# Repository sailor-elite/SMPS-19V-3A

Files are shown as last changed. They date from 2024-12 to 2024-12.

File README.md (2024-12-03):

# SMPS SPECIFICATIONS
- Input Voltage: 230V AC (rectified to ~325V DC)
- Output Voltage: 19V DC
- Output Current: 3A
- Output Power: Up to 60W (maximum)

# SCHEMATIC DIAGRAM

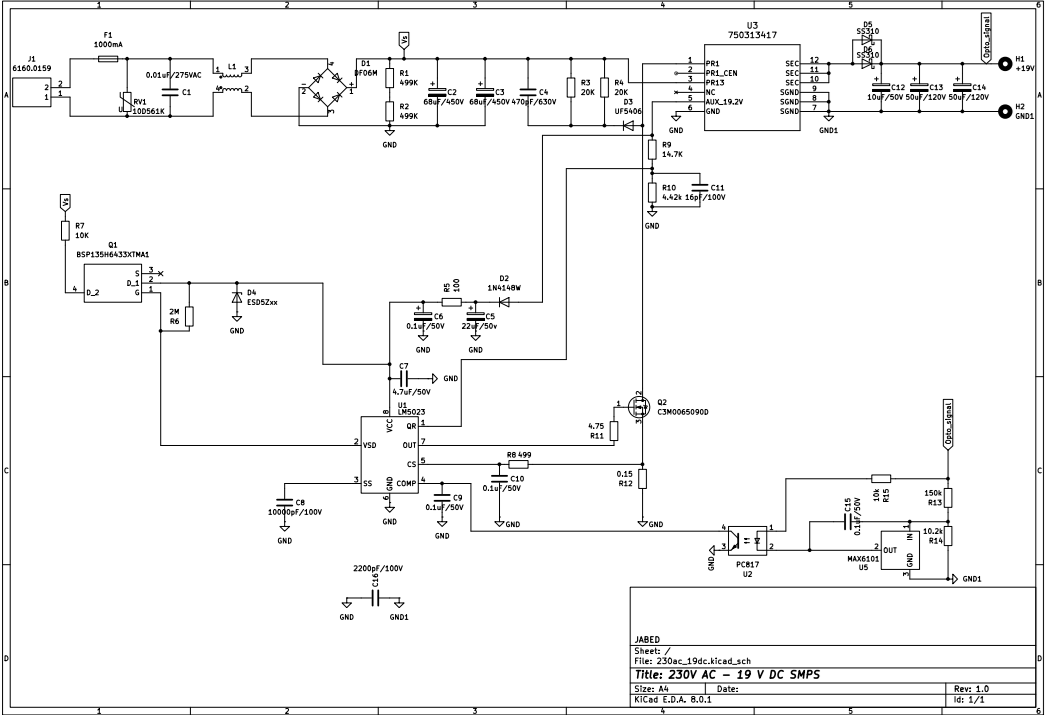
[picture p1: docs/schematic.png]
Schematic


# PCB 3D VIEW

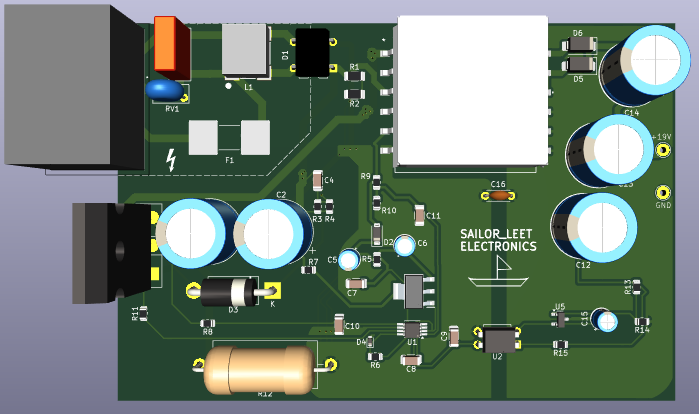
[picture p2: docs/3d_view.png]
PCB_3D_VIEW


# CALCULATION

### Transformer Turns Ratio Calculation

To determine the turns ratio of a transformer, use the following formula:

Np / Ns = Vin / (Vout + Vd)

Where:  
- **\(N_p\)**: Number of primary winding turns  
- **\(N_s\)**: Number of secondary winding turns  
- **\(V_in\)**: Input voltage to the transformer (325V DC in this example)  
- **\(V_out\)**: Desired output voltage (19V DC in this case)  
- **\(V_d\)**: Voltage drop across the secondary diode (approximately 0.5V for a Schottky diode)  

#### Example Calculation:

For an output voltage of 19V:

Np / Ns = 325V / (19V + 0.5V)

Np / Ns = 325 / 19.5 ≈ 16.66

Thus, the primary-to-secondary turns ratio is approximately **17:1**.

### Turns Ratio Calculation

The number of primary turns (**Np**) can be calculated using the volt-second balance equation:

Np = (Vin × ton) / (Bmax × Ae)

Where:  
- **Vin**: Input voltage (325V)  
- **ton**: On-time of the switch (calculated based on the duty cycle, typically 50% at maximum load)  
- **Bmax**: Maximum magnetic flux density (e.g., 2000 Gauss or 0.2T for ferrite cores)  
- **Ae**: Effective cross-sectional area of the core  

#### Example Calculation:

For a switching frequency of **130 kHz** (period = 7.7µs) and a 50% duty cycle, the on-time (\(ton\)) is:

ton = 50% of 7.7µs = 3.35µs

Assume the following parameters for an ETD39 core:  
- **Bmax = 0.2T**  
- **Ae = 125mm² (125 × 10⁻⁶ m²)**  

Substitute the values into the formula:

Np = (325V × 3.35µs) / (0.2T × 125 × 10⁻⁶ m²) Np ≈ 43.5 turns

Thus, the primary winding requires approximately **44 turns**.

### Number of Secondary Turns Calculation

Using the turns ratio and the calculated number of primary turns, the number of secondary turns (**Ns**) can be calculated as follows:

Ns = Np / Turns Ratio

Where:  
- **Np**: Number of primary turns (calculated previously as 85 turns)  
- **Turns Ratio**: Primary-to-secondary turns ratio (17:1 in this example)  

#### Example Calculation:

Substitute the values into the formula:

Ns = 44 / 17 Ns ≈ 2.5 turns

So the turns number is **3**.
### Reference Voltage

Using a voltage divider with resistors of **150 kΩ** and **10.2 kΩ** creates the following ratio:

Vout = Vin * (R_lower / (R_upper + R_lower))

Where:  
- **Vin**: Input voltage  
- **R_lower**: Resistor connected to the ground (10.2 kΩ)  
- **R_upper**: Resistor connected to the input voltage (150 kΩ)  

#### Example Calculation:

For an input voltage of **19V**:

Vout = 19V * (10.2 kΩ / (150 kΩ + 10.2 kΩ))

Vout = 19V * (10.2 / 160.2) ≈ 1.21V

This is very close to the reference voltage of the **MAX6101**, which is **1.25V**.

# COMPONENTS
| Component | Value | Package | Quantity |
|---|---|---|---|
| C1 | 0.01uF/275VAC  | Capacitor_THT:C_Rect_L10.0mm_W4.0mm_P7.50mm_MKS4 | 1 |
| C2, C3 | 68uF/450V | Capacitor_THT:CP_Radial_D12.5mm_P7.50mm | 2 |
| C4 | 470pF/630V | Capacitor_SMD:C_1206_3216Metric | 1 |
| C5 | 22uF/50V | Capacitor_THT:CP_Radial_D4.0mm_P2.00mm | 1 |
| C6, C9, C10, C15 | 0.1uF/50V | -- mixed values -- | 4 |
| C7 | 4.7uF/50V | Capacitor_SMD:C_1206_3216Metric | 1 |
| C8 | 10000pF/100V | Capacitor_SMD:C_1206_3216Metric | 1 |
| C11 | 16pF/100V | Capacitor_SMD:C_1206_3216Metric | 1 |
| C12 | 10uF/50V | Capacitor_THT:CP_Radial_D12.5mm_P7.50mm | 1 |
| C13, C14 | 50uF/120V | Capacitor_THT:CP_Radial_D12.5mm_P7.50mm | 2 |
| C16 | 2200pF/100V | Capacitor_THT:C_Disc_D4.3mm_W1.9mm_P5.00mm | 1 |
| D1 | DF06M | Diode_THT:Diode_Bridge_DIP-4_W7.62mm_P5.08mm | 1 |
| D2 | 1N4148W | Diode_SMD:D_SOD-123 | 1 |
| D3 | UF5406 | Diode_THT:D_DO-201AD_P15.24mm_Horizontal | 1 |
| D4 | ESD5Zxx | Diode_SMD:D_SOD-523 | 1 |
| D5, D6 | SS310 | Diode_SMD:D_SMA | 2 |
| F1 | 1000mA | Fuse:Fuse_Littelfuse-NANO2-462 | 1 |
| J1 | 6160.0159 | private:61600159 | 1 |
| L1 | L_Coupled_1342 | private:WE-SL5_HC | 1 |
| Q1 | BSP135H6433XTMA1| private:SOT230P700X180-4N | 1 |
| Q2 | C3M0065090D | Package_TO_SOT_THT:TO-247-3_Vertical | 1 |
| R1, R2 | 499K | Resistor_SMD:R_1206_3216Metric | 2 |
| R3, R4 | 20K | Resistor_SMD:R_0805_2012Metric | 2 |
| R5 | 100 | Resistor_SMD:R_0805_2012Metric | 1 |
| R6 | 2M | Resistor_SMD:R_0805_2012Metric | 1 |
| R7 | 10K | Resistor_SMD:R_0805_2012Metric | 1 |
| R8 | 499 | Resistor_SMD:R_0805_2012Metric | 1 |
| R9 | 14.7K | Resistor_SMD:R_0805_2012Metric | 1 |
| R10 | 4.42k | Resistor_SMD:R_0805_2012Metric | 1 |
| R11 | 4.75 | Resistor_SMD:R_0805_2012Metric | 1 |
| R12 | 0.15 | Resistor_THT:R_Axial_DIN0922_L20.0mm_D9.0mm_P25.40mm_Horizontal | 1 |
| R13 | 150k | Resistor_SMD:R_0805_2012Metric | 1 |
| R14 | 10.2k | Resistor_SMD:R_0805_2012Metric | 1 |
| R15 | 10k | Resistor_SMD:R_0805_2012Metric | 1 |
| RV1 | 10D561K | Varistor:RV_Disc_D7mm_W3.6mm_P5mm | 1 |
| U1 | LM5023 | Package_SO:VSSOP-8_3.0x3.0mm_P0.65mm | 1 |
| U2 | PC817 | Package_DIP:DIP-4_W7.62mm | 1 |
| U3 | 750313417 | private:SMD_13417_WRE | 1 |
| U5 | MAX6101 | Package_TO_SOT_SMD:SOT-23 | 1 |

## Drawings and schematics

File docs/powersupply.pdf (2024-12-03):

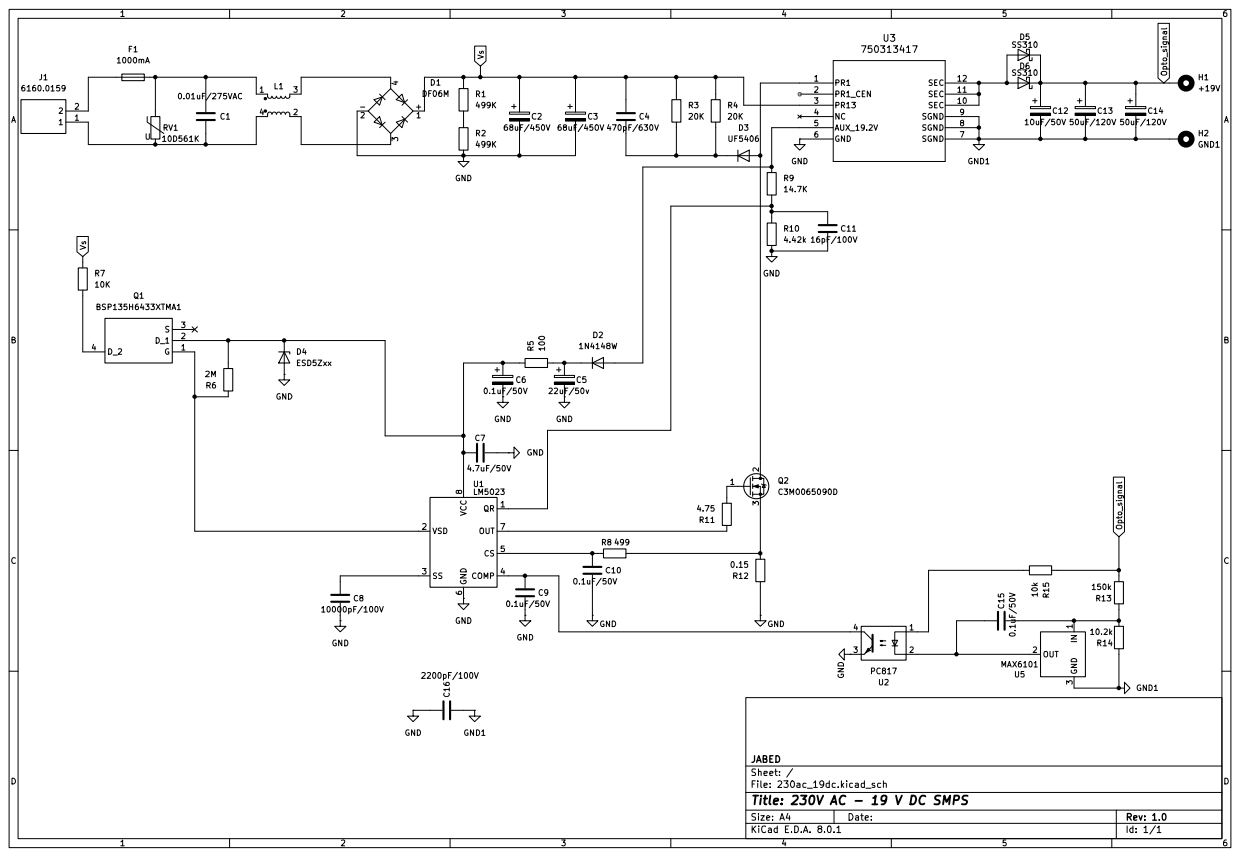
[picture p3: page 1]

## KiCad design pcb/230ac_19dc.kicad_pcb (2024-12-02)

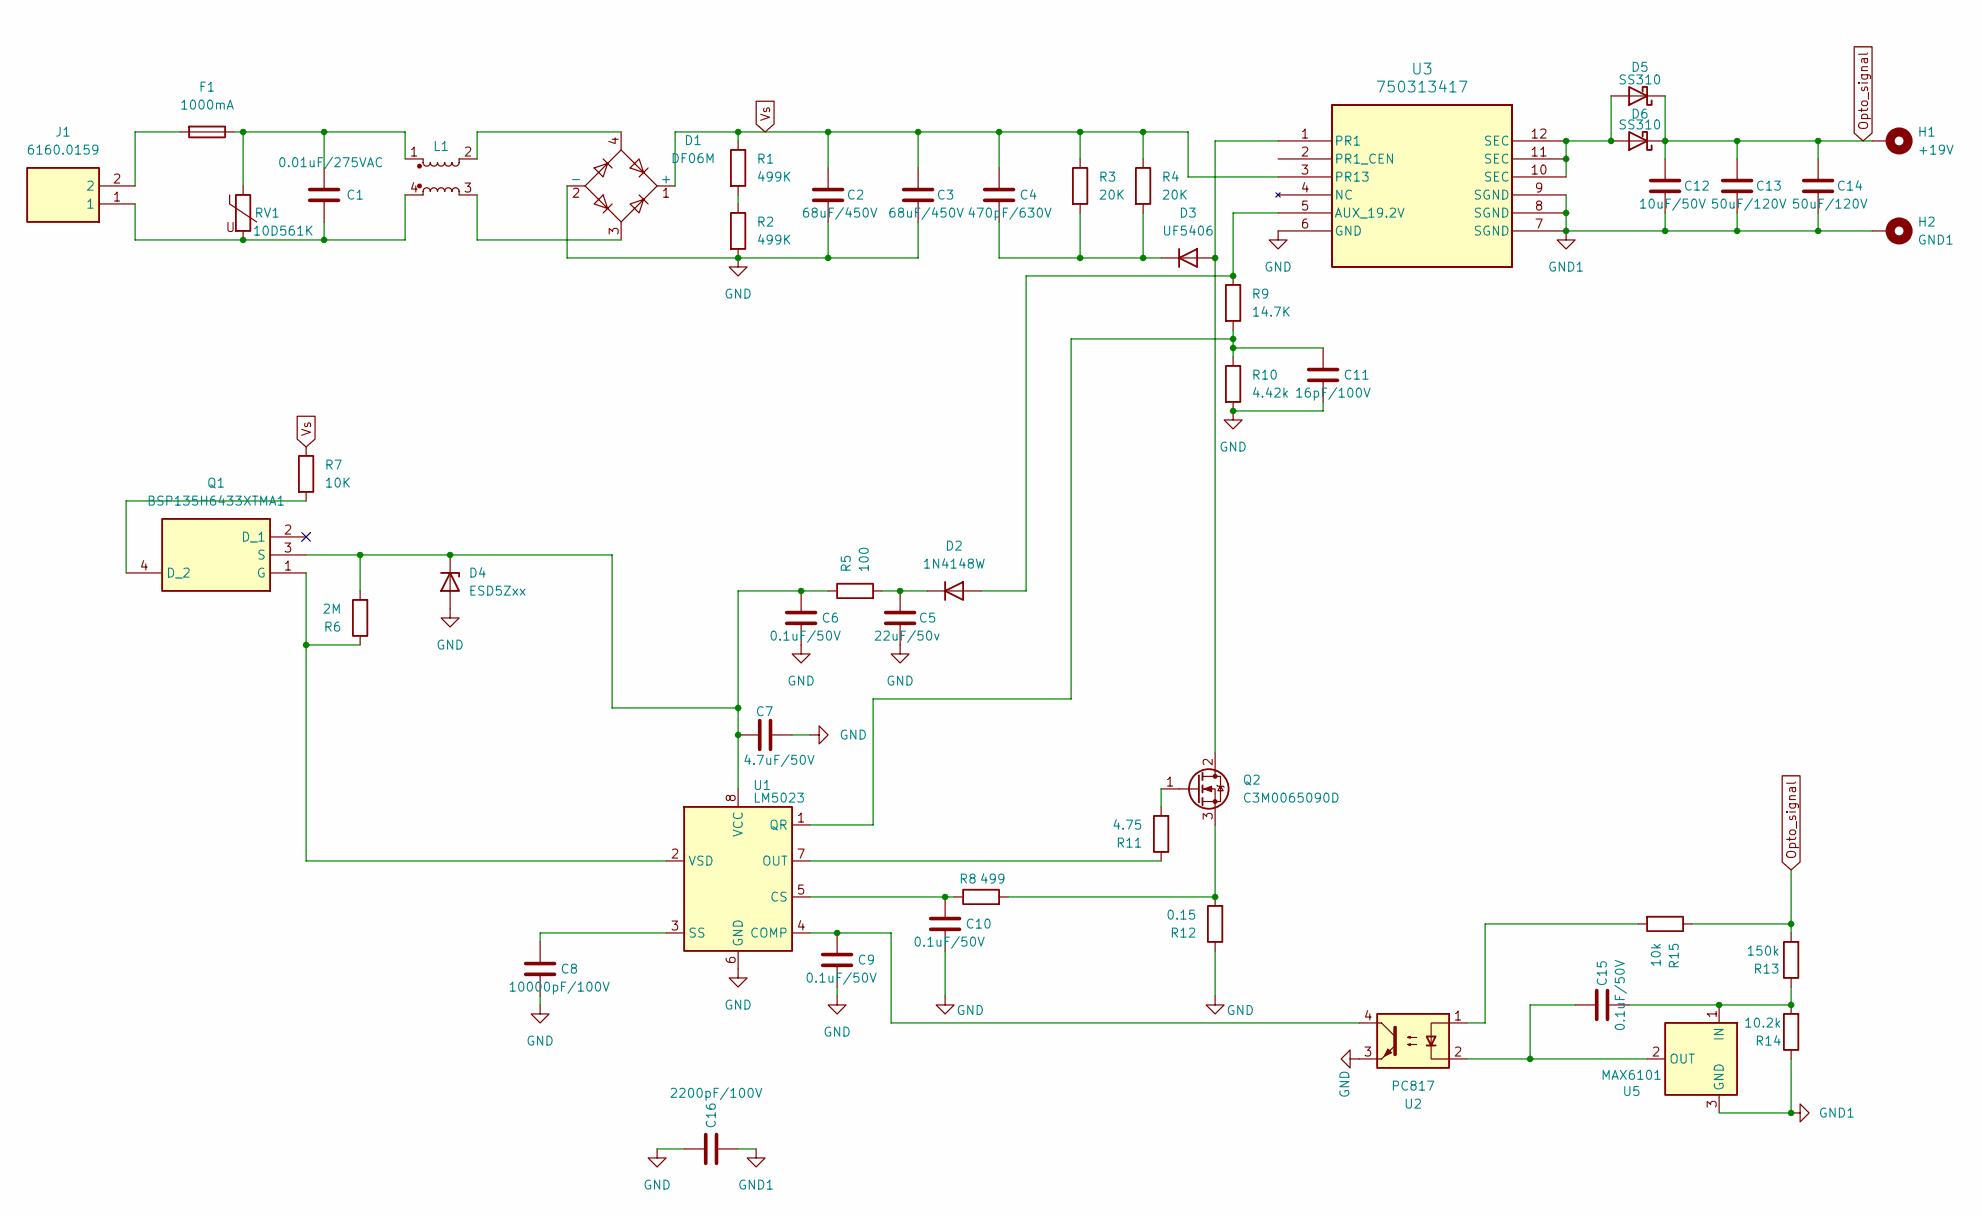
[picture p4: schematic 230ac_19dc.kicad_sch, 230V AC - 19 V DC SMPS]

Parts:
C1: 0.01uF/275VAC; C_Rect_L10.0mm_W4.0mm_P7.50mm_MKS4
C2, C3: 68uF/450V; CP_Radial_D12.5mm_P7.50mm
C4: 470pF/630V; C_1206_3216Metric
C5: 22uF/50v; CP_Radial_D4.0mm_P2.00mm
C6, C15: 0.1uF/50V; CP_Radial_D4.0mm_P2.00mm
C7: 4.7uF/50V; C_1206_3216Metric
C8: 10000pF/100V; C_1206_3216Metric
C9, C10: 0.1uF/50V; C_1206_3216Metric
C11: 16pF/100V; C_1206_3216Metric
C12: 10uF/50V; CP_Radial_D12.5mm_P7.50mm
C13, C14: 50uF/120V; CP_Radial_D12.5mm_P7.50mm
C16: 2200pF/100V; C_Disc_D4.3mm_W1.9mm_P5.00mm
D1: DF06M; Diode_Bridge_DIP-4_W7.62mm_P5.08mm
D2: 1N4148W; D_SOD-123
D3: UF5406; D_DO-201AD_P15.24mm_Horizontal
D4: ESD5Zxx; D_SOD-523
D5, D6: SS310; D_SMA
F1: 1000mA; Fuse_Littelfuse-NANO2-462
H1: +19V; TestPoint_THTPad_D2.5mm_Drill1.2mm
H2: GND1; TestPoint_THTPad_D2.5mm_Drill1.2mm
J1: 6160.0159; 61600159; Mouser Part Number 693-6160.0159
L1: L_Coupled_1342; WE-SL5_HC
Q1: BSP135H6433XTMA1; SOT230P700X180-4N; Mouser Part Number 726-BSP135H6433XTMA1
Q2: C3M0065090D; TO-247-3_Vertical
R1, R2: 499K; R_1206_3216Metric
R3, R4: 20K; R_0805_2012Metric
R5: 100; R_0805_2012Metric
R6: 2M; R_0805_2012Metric
R7: 10K; R_0805_2012Metric
R8: 499; R_0805_2012Metric
R9: 14.7K; R_0805_2012Metric
R10: 4.42k; R_0805_2012Metric
R11: 4.75; R_0805_2012Metric
R12: 0.15; R_Axial_DIN0922_L20.0mm_D9.0mm_P25.40mm_Horizontal
R13: 150k; R_0805_2012Metric
R14: 10.2k; R_0805_2012Metric
R15: 10k; R_0805_2012Metric
RV1: 10D561K; RV_Disc_D7mm_W3.6mm_P5mm
U1: LM5023; VSSOP-8_3.0x3.0mm_P0.65mm
U2: PC817; DIP-4_W7.62mm
U3: 750313417; SMD_13417_WRE
U5: MAX6101; SOT-23

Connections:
GND: C2.2, C3.2, C5.2, C6.2, C7.2, C8.2, C9.2, C10.2, C11.2, C16.1, D1.2 (-), D4.2 (A), R2.2, R10.2, R12.1, U1.6 (GND), U2.3, U3.6 (GND)
GND1: C12.2, C13.2, C14.2, C16.2, H2.1, R14.1, U3.7 (SGND), U3.8 (SGND), U3.9 (SGND), U5.3 (GND)
unnamed: C1.1, F1.1, L1.1, RV1.1
unnamed: C1.2, J1.1, L1.4, RV1.2
unnamed: D1.3, L1.3
unnamed: D1.4, L1.2
unnamed: D2.2 (A), R9.1, U3.5 (AUX_19.2V)
unnamed: C5.1, D2.1 (K), R5.2
unnamed: D3.2 (A), Q2.2 (D), U3.1 (PR1)
unnamed: C4.2, D3.1 (K), R3.2, R4.2
unnamed: C6.1, C7.1, D4.1 (K), Q1.3 (S), R5.1, R6.2, U1.8 (VCC)
unnamed: D5.2 (A), D6.2 (A), U3.10 (SEC), U3.11 (SEC), U3.12 (SEC)
unnamed: F1.2, J1.2
unnamed: Q1.4 (D_2), R7.2
unnamed: Q1.1 (G), R6.1, U1.2 (VSD)
unnamed: Q2.1 (G), R11.2
unnamed: Q2.3 (S), R8.2, R12.2
unnamed: R1.2, R2.1
unnamed: R15.2, U2.1
unnamed: C9.1, U1.4 (COMP), U2.4
unnamed: C10.1, R8.1, U1.5 (CS)
unnamed: R11.1, U1.7 (OUT)
unnamed: C11.1, R9.2, R10.1, U1.1 (QR)
unnamed: C8.1, U1.3 (SS)
unnamed: C15.2, R13.1, R14.2, U5.1 (IN)
unnamed: C15.1, U2.2, U5.2 (OUT)
Opto_signal: C12.1, C13.1, C14.1, D5.1 (K), D6.1 (K), H1.1, R13.2, R15.1
Vs: C2.1, C3.1, C4.1, D1.1 (+), R1.1, R3.1, R4.1, R7.1, U3.3 (PR13)

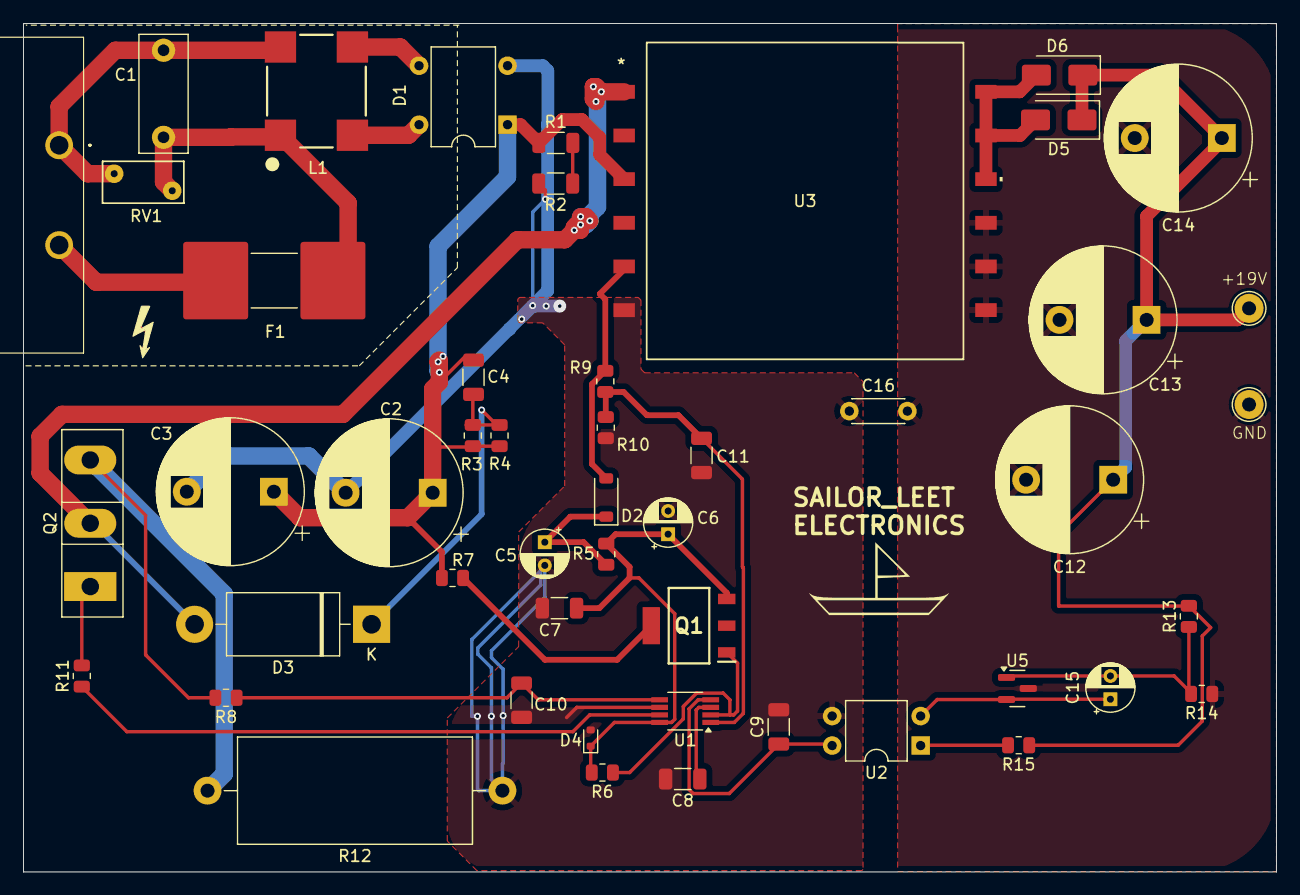
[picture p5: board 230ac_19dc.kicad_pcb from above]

Board: 2 copper layers, 107.9 x 73.1 mm, 49 parts (0 on the bottom side), 28 nets.

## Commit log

2024-11-27 Rev v1.0
    Only SMPS schematic ( without PCB design)
    [230ac_19dc.kicad_sch]
2024-12-02 Rev 1.1
    Created PCB design, minor changes to schematic diagram
    [230ac_19dc.kicad_pcb, 230ac_19dc.kicad_sch]
2024-12-03 Rev 1.2
    Minor changes in schematic - capacitor symbols
    [230ac_19dc.kicad_sch]
